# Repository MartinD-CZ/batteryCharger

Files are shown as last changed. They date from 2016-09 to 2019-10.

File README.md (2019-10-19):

# AVR-based universal battery charger

**UPDATE!** By popular request, I will be releasing a new version. Check [this post](http://embedblog.eu/?p=204) for more information.  
**UPDATE #2** I've abandoned the project, mostly because of time. What I have so far has been put into the 'unfinished-arduino' folder.

###### Overall
The charger is based on Atmega 328 (because it is dirt cheap) and utilizes its PWM to drive a FET, used as buck converter. There is also an 5110 LCD (again, less than 2 USD on Ebay) to show some basic menus and stuff. Most of the settings are adjustable on the go, so once you build and program it, you can use it without further reprogramming for all battery types and so on.

###### Batteries:
The charger supports all of the most used battery types - that is in my opinion NiCd, NiMH, Li-Ion and SLA. Li-Ion and SLA are charged in constant current-constant voltage mode, while Nickel based batteries are charged with constant current and terminated by about 5 methods (time out, overvoltage, overtemperature, -dV/dT, user termination). I have been using the charger for about a month before posting it here (tested everything except SLA, don’t have those on hand) and everything seems to work seamlessly. Maximum charging current is 3A, maximum charging voltage is almost Vin (that’s about 18V in my setup).

###### Discharge
The charger also comes with a discharge circuitry, used to:
	A) Measure battery capacity
	B) Discharge batteries before charging (useful with NiMH batteries to neutralize their memory effect)
The discharging current is fully adjustable from 0 to 3 amps, with undervoltage protection (again, fully adjustable). There is a small fan, which is automatically switched on when thermal power dissipation is bigger than 2 watts (you can change that, it depends on the size of your heatsink).

###### Power supply
Also in the menu you can find "constant C", "constant V" and "power supply" options. They provide you with simple power supply, useful for SOME applications. Because of the MCU limitations, the transient response time is relatively long, but on loads that do not change quickly, the MCU will react quickly enough. Maximum output voltage of the power supply is almost Vin and output current 3 A.

###### Project
This started as my own personal build, but since I spent a lot of time on it, I decided to publish it. For me, it works well, even for precise charging lithium batteries. 
It is inspired by AVR450, but 99% of the code is my work. I also used 5110 LCD driver library from Radu Motisan, see the 5110 files for credit.
I would like to hear some feedback on this project. What do you think about it? The total cost was less than 10 USD, which, I believe, is dirt cheap. Also, if there will be interest, I am thinking about porting this to STM32, as they are superior to 8-bit AVR and still very cheap. I would also include balancing circuitry. What do you think about that?

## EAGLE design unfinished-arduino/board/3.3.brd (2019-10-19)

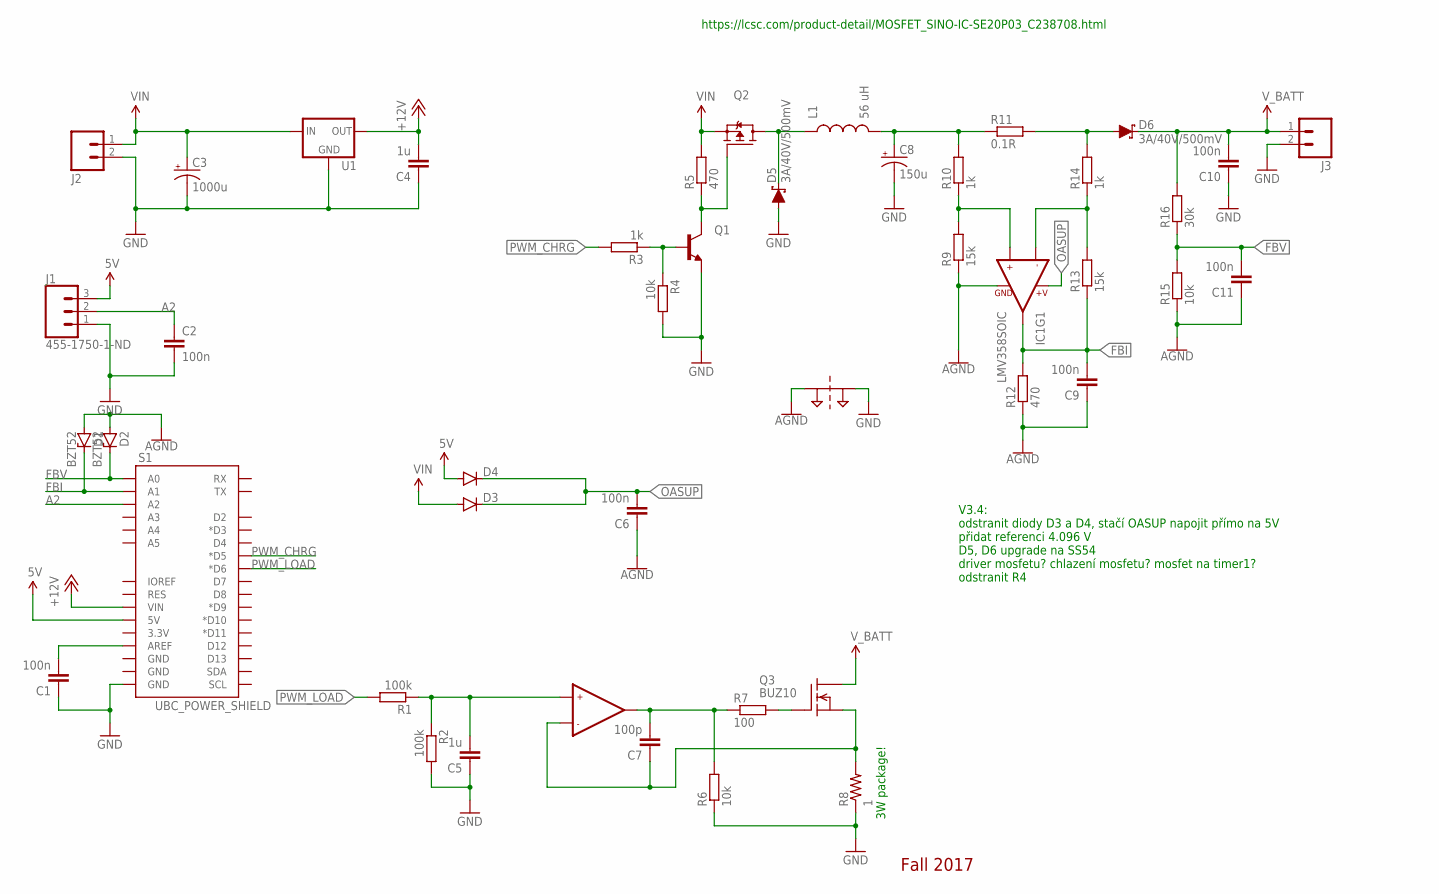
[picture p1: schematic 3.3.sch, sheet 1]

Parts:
C1, C2, C6, C9, C10, C11: 100n; C1206
C3: 1000u; CPOL-RADIAL-1000UF-25V
C4, C5: 1u; C1206
C7: 100p; C1206
C8: 150u; CPOL-RADIAL-100UF-25V
D1, D2: BZT52; SOD80C
D3, D4: DIODE-MINIMELF; MINIMELF
D5, D6: 3A/40V/500mV; SMA-DIODE
IC1: LMV358SOIC; SO08
J1: 455-1750-1-ND; 1X03
J2, J3: M025MM; SCREWTERMINAL-5MM-2
L1: 56 uH; CDRH125
PT1: 2PT_GND_TIE
Q1: 2N3904-MMBT; SOT23
Q2: FDD4141TO252; TO252
Q3: BUZ10; TO220
R1, R2: 100k; R1206
R3, R10, R14: 1k; R1206
R4, R6, R15: 10k; R1206
R5, R12: 470; R1206
R7: 100; R1206
R8: 1; 0617/22
R9, R13: 15k; R1206
R11: 0.1R; 0414/15
R16: 30k; R1206
S1: UBC_POWER_SHIELD; UBC_POWER
U1: V_REG_78XXSIDE; 78XXL

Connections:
5V: D4.A, J1.3, S1.5V; also elsewhere on the board
+12V: C4.2, S1.VIN, U1.OUT
A2: C2.1, J1.2, S1.A2
AGND: C6.1, C9.1, C11.1, D1.A, D2.A, IC1.4 (GND), PT1.P$1, R9.1, R12.1, R15.1
FBI: C9.2, D1.C, IC1.1 (OUT1), R12.2, R13.1, S1.A1
FBV: C11.2, D2.C, R15.2, R16.1, S1.A0
GND: C1.1, C2.2, C3.2 (-), C4.1, C5.1, C8.2 (-), C10.1, D5.A, J1.1, J2.2, J3.2, PT1.P$2, Q1.2 (E), R2.2, R4.2, R6.1, R8.1, S1.GND@0 (GND), U1.GND; also elsewhere on the board
unnamed: C8.1 (+), L1.2, R10.2, R11.1
unnamed: C1.2, S1.AREF
unnamed: IC1.3 (+IN1), R9.2, R10.1
unnamed: IC1.2 (-IN1), R13.2, R14.1
unnamed: D5.C, L1.1, Q2.3 (D)
unnamed: D6.A, R11.2, R14.2
unnamed: C7.2, IC1.7 (OUT2), R6.2, R7.1
unnamed: Q1.3 (C), Q2.1 (G), R5.1
unnamed: Q3.1 (G), R7.2
unnamed: C7.1, IC1.6 (-IN2), Q3.3 (S), R8.2
unnamed: C5.2, IC1.5 (+IN2), R1.1, R2.1
unnamed: Q1.1 (B), R3.1, R4.1
OASUP: C6.2, D3.C, D4.C, IC1.8 (+V)
PWM_CHRG: R3.2, S1.D5 (*D5)
PWM_LOAD: R1.2, S1.D6 (*D6)
VIN: C3.1 (+), D3.A, J2.1, Q2.2 (S), R5.2, U1.IN
V_BATT: C10.2, D6.C, J3.1, Q3.2 (D), R16.2

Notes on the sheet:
3W package!
Fall 2017
https://lcsc.com/product-detail/MOSFET_SINO-IC-SE20P03_C238708.html
V3.4: odstranit diody D3 a D4, stačí OASUP napojit přímo na 5V přidat referenci 4.096 V D5, D6 upgrade na SS54 driver mosfetu? chlazení mosfetu? mosfet na timer1? odstranit R4

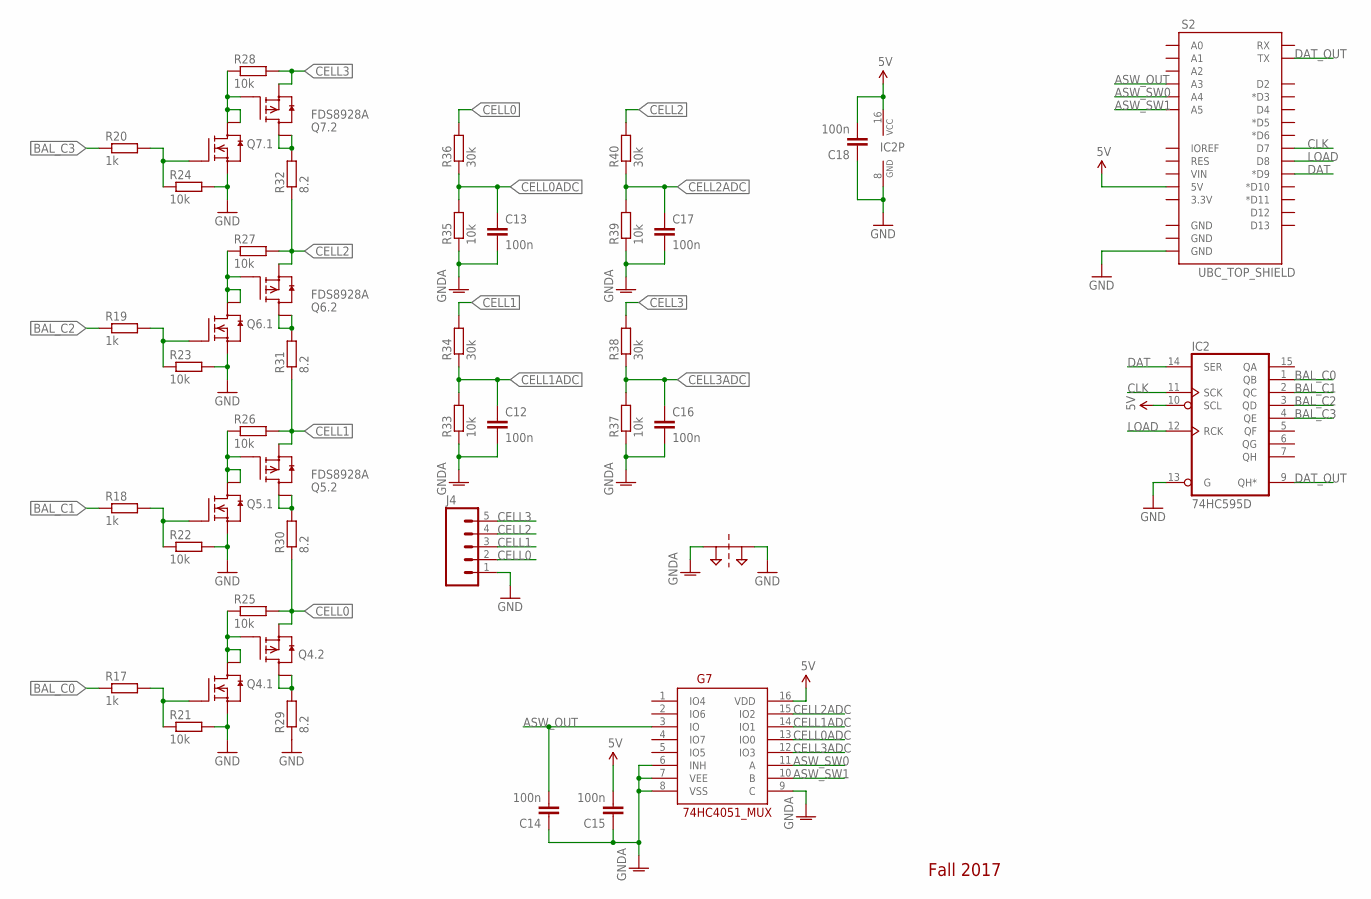
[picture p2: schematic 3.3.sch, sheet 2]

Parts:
C12, C13, C14, C15, C16, C17: 100n; C1206
C18: 100n; 1206
G7: 74HC4051_MUX; SO16
IC2: 74HC595D; SO16
J4: M05PTH; 1X05
PT2: 2PT_GND_TIE
Q4, Q5, Q6, Q7: FDS8928A; SO-8
R17, R18, R19, R20: 1k; R1206
R21, R22, R23, R24, R25, R26, R27, R28, R33, R35, R37, R39: 10k; R1206
R29, R30, R31, R32: 8.2; R2512
R34, R36, R38, R40: 30k; R1206
S2: UBC_TOP_SHIELD; UBC_TOP

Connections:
5V: C15.2, C18.2, G7.16 (VDD), IC2.10 (SCL), IC2.16 (VCC), S2.5V; also elsewhere on the board
ASW_OUT: C14.2, G7.3 (IO), S2.A3
ASW_SW0: G7.11 (A), S2.A4
ASW_SW1: G7.10 (B), S2.A5
BAL_C0: IC2.1 (QB), R17.1
BAL_C1: IC2.2 (QC), R18.1
BAL_C2: IC2.3 (QD), R19.1
BAL_C3: IC2.4 (QE), R20.1
CELL0: J4.2, Q4.3 (S), R25.2, R30.1, R36.2
CELL0ADC: C13.1, G7.13 (IO0), R35.2, R36.1
CELL1: J4.3, Q5.3 (S), R26.2, R31.1, R34.2
CELL1ADC: C12.1, G7.14 (IO1), R33.2, R34.1
CELL2: J4.4, Q6.3 (S), R27.2, R32.1, R40.2
CELL2ADC: C17.1, G7.15 (IO2), R39.2, R40.1
CELL3: J4.5, Q7.3 (S), R28.2, R38.2
CELL3ADC: C16.1, G7.12 (IO3), R37.2, R38.1
CLK: IC2.11 (SCK), S2.D7
DAT: IC2.14 (SER), S2.D9 (*D9)
DAT_OUT: IC2.9 (QH*), S2.TX
GND: C18.1, IC2.8 (GND), IC2.13 (G), J4.1, PT2.P$2, Q4.1 (S), Q5.1 (S), Q6.1 (S), Q7.1 (S), R21.2, R22.2, R23.2, R24.2, R29.1, S2.GND@0 (GND); also elsewhere on the board
GNDA: C12.2, C13.2, C14.1, C15.1, C16.2, C17.2, G7.6 (INH), G7.7 (VEE), G7.8 (VSS), G7.9 (C), PT2.P$1, R33.1, R35.1, R37.1, R39.1
LOAD: IC2.12 (RCK), S2.D8
unnamed: Q4.2 (G), R17.2, R21.1
unnamed: Q4.5 (D), Q4.6 (D), R29.2
unnamed: Q5.2 (G), R18.2, R22.1
unnamed: Q5.4 (G), Q5.7 (D), Q5.8 (D), R26.1
unnamed: Q5.5 (D), Q5.6 (D), R30.2
unnamed: Q6.2 (G), R19.2, R23.1
unnamed: Q6.4 (G), Q6.7 (D), Q6.8 (D), R27.1
unnamed: Q6.5 (D), Q6.6 (D), R31.2
unnamed: Q7.2 (G), R20.2, R24.1
unnamed: Q7.4 (G), Q7.7 (D), Q7.8 (D), R28.1
unnamed: Q7.5 (D), Q7.6 (D), R32.2
unnamed: Q4.4 (G), Q4.7 (D), Q4.8 (D), R25.1

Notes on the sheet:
Fall 2017

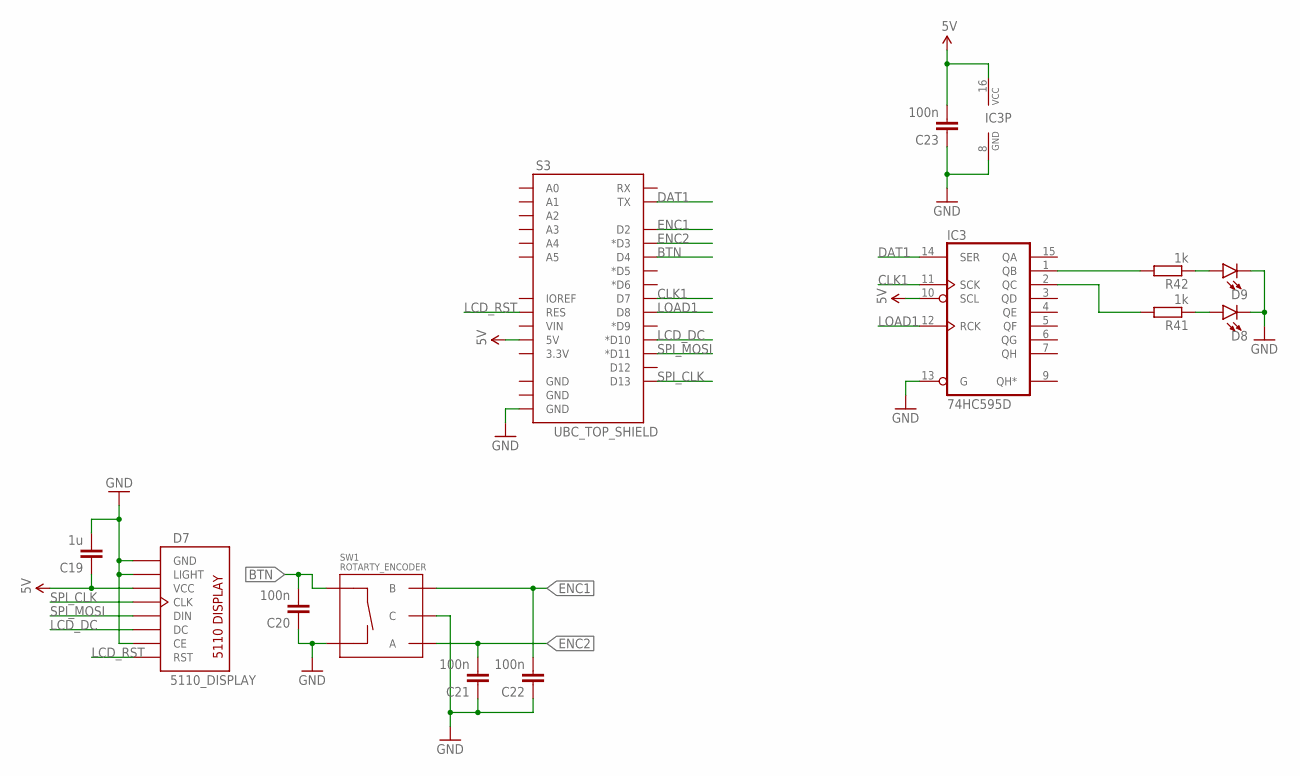
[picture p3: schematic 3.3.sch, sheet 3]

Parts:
C19: 1u; 1206
C20, C21, C22, C23: 100n; 1206
D7: 5110_DISPLAY; 5110_LAYOUT
D8, D9: LED5MM; LED_5MM
IC3: 74HC595D; SO16
R41, R42: 1k; R1206
S3: UBC_TOP_SHIELD; UBC_TOP
SW1: ROTARTY_ENCODER; ROTARY_ENC_PLAIN

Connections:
5V: C19.1, C23.2, D7.VCC, IC3.10 (SCL), IC3.16 (VCC), S3.5V; also elsewhere on the board
BTN: C20.2, S3.D4, SW1.SW+
CLK1: IC3.11 (SCK), S3.D7
DAT1: IC3.14 (SER), S3.TX
ENC1: C22.2, S3.D2, SW1.B
ENC2: C21.2, S3.D3 (*D3), SW1.A
GND: C19.2, C20.1, C21.1, C22.1, C23.1, D7.CE, D7.GND, D7.LIGHT, D8.K (C), D9.K (C), IC3.8 (GND), IC3.13 (G), S3.GND@0 (GND), SW1.C, SW1.SW-; also elsewhere on the board
LCD_DC: D7.DC, S3.D10 (*D10)
LCD_RST: D7.RST, S3.RES
LOAD1: IC3.12 (RCK), S3.D8
unnamed: IC3.1 (QB), R42.2
unnamed: IC3.2 (QC), R41.2
unnamed: D9.A, R42.1
unnamed: D8.A, R41.1
SPI_CLK: D7.CLK, S3.D13
SPI_MOSI: D7.DIN, S3.D11 (*D11)

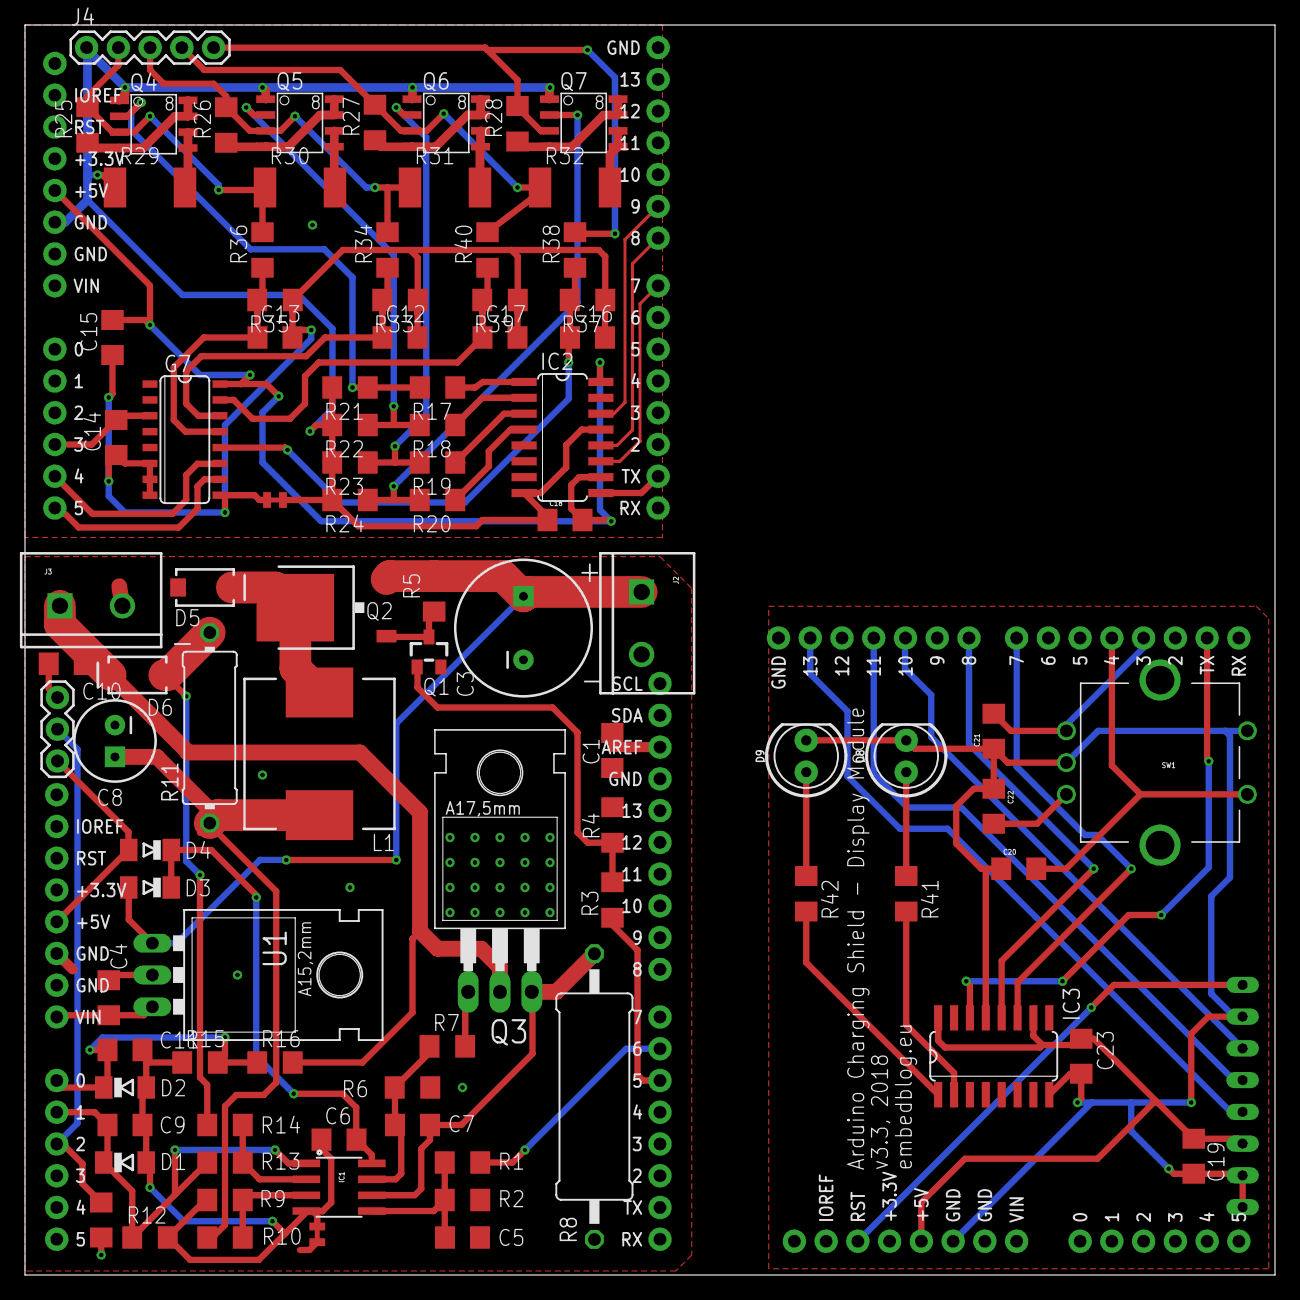
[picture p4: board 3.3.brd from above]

Board: 2 copper layers, 100.0 x 100.0 mm, 97 parts (0 on the bottom side), 70 nets.

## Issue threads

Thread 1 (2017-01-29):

V2

boelle, 2017-01-29:
Hi

have you started on V2 ?

I was looking for a charger most like yours, but have ideas for extra features

I have one of these old car chargers that can output about 15A.. would it be easy to expand the charger so it could go this high?

and if we fit one of those full graphics displays we would have a more space plus we could log things to a sd card?

just thoughts

boelle, 2017-01-29:
i read a bit about desulfators, they are great for car batteries that are going bad, sometimes you can bring them to life

and interesting a few people on the internet have used them with nimh cell's too

this one looks interesting: http://www.instructables.com/id/Desulfator-for-12V-Car-Batteries-in-an-Altoids-Ti/

MartinD-CZ, 2017-01-29:
Hi,

well, version 2 is scheduled, but I am currently very busy, so I think it
will not be out before the end od February. Well, theoretically it is only
a matter of changing components and their values for this thing to output
15A, but I have never tried more than 5A...
Well, of course, a better display would be a fine addition. But I was going
for as-cheap-as-possible, and I think that enough information fits on the
screen.

Regards,
Martin

On 29 January 2017 at 20:43, Bo Herrmannsen <notifications@github.com>
wrote:

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

boelle, 2017-01-29:
oki, could you put a reply more in here when you are about to publish it?

i might want to draw it in eagle schematic and do a real pcb of it.

would the desulfator idea be bad? and can it still fit on the same screen?

boelle, 2017-01-29:
oh.. i forgot... for the first version i see that you used eagle schematic also

how far have you come with V2? do you need to draw it first?

and also have you published the files for v1.3 ?

MartinD-CZ, 2017-01-30:
Hi,

as far as version 2 goes, I have the product working, what remains is
drawing the schematics, proper PCB layout and all the documentation. As for
the desulfator, I will have a look at it tomorrow, today I am busy.

Martin.

On 29 January 2017 at 21:50, Bo Herrmannsen <notifications@github.com>
wrote:

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

boelle, 2017-01-30:
np... cant wait to see what you have come up with :-D

sjdaliyan, 2018-03-17:
Any news of v2?

MartinD-CZ, 2018-03-17:
Hi,

well, I din't advance on it much. I have the board drawn, and manufactured,
but I did not get the time to populate, test, program and write about it.
So for now, the project is on hold, as I am working on different projects
now...
If I ever get back to it (and I want, don't get me wrong), I will certainly
publish it... But I do not have a clue as to when that might be.

Regards,
Martin

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

goosenphil, 2018-11-13:
Hi, since you've drawn the schematic in order to make the PCB, could you share the schematic and code with us in the meantime?

Since this is an open source project, some of us can take on the tasks you have not been able to reach.

It's fine if it's unfinished, we just want to see what you have so far.

Closed 2019-03-19.

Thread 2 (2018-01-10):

layout or schematics

repcsi, 2018-01-10:
Hello Martin,

I was wondering if there was a layout or schematics file in your project, because I couldn't find it in the atmel studio project directory.

Thanks!

MartinD-CZ, 2018-01-10:
Hi,

you can find the schematics on Instructables. However, the quality is very
poor. Anyways, this is an old project and I am working on a successor, so
if you wait a few weeks, you might be able to build the new version instead
of the old...

Regards,
Martin

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

Sausages69, 2018-01-14:
Hi Martin. This looks like a fantastic project!
Really looking forward to checking out the new version.

xtalgrwr, 2022-07-27:
Hello Martin,
Are you still active with the new version? Was there ever a PCB file?
Thank you. Please let us know.

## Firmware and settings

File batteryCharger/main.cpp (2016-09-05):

/*
 * AVR MultiChemistry charger
 * main.cpp file
 * (C) Martin Danek, 2016
 * madanek@post.cz
 * github.com/MartinD-CZ/AVRcharger
 */ 

#include <avr/wdt.h>
void wdt_init(void) __attribute__((naked)) __attribute__((section(".init3")));		//disables watchdog on startup

#include <inttypes.h>
#include "uart/uart.h"
#include <avr/io.h>
#include "header.h"
#include <util/delay.h>
#include <avr/interrupt.h>
#include "display/5110.h"
#include "display/menu.h"
extern LCD_5110 lcd;
#include "adc.h"
#include "batteryTypes/constantCV.h"
#include "batteryTypes/NiMH.h"
#include "functions.h"

//variables
volatile bool secondFlag;

char* mainMenuName = "Select mode: ";
char* mainMenuItems[5] = {"CHARGE", "DISCHARGE", "POWER SUPPLY", "ABOUT", "RESTART"};
char* chemistryMenuName = "Battery type:";
char* chemistryMenuItems[5] = {"Li-Ion/SLA", "NiCd/NiMH", "CONST V", "CONST C", "BACK TO MENU"};

int main(void)
{
    PORTD |= (1<<PORTD2)|(1<<PORTD3)|(1<<PORTD4);	//button pull up resistors 
	PORTB |= (1<<PORTB1)|(1<<PORTB2);

	DDRD |= (1<<DDD7);				//LED pins as outputs
	DDRB |= (1<<DDB0);	

	DDRD |= (1<<DDD5)|(1<<DDD6);	//pwm pins as outputs

	DDRC |= (1<<DDC4)|(1<<DDC5);	//UART and fan pins as outputs
	UART_PIN_HIGH;

	//setting up timer 1
	TCNT1 = 0;
	OCR1A = 19531;				//set the overflow value (overflow each second)
	TIMSK1 |= (1<<OCIE1A);		//enable CTC interrupt
	sei();						//globally enable interrupts

	ADC_setup();				
	lcdInit();					

	while (1) 
    {
		lcd.lcd_clear();
		float maxC, maxV, disC, minV;

		switch (drawSelectionMenu(mainMenuName, mainMenuItems))
		{
			case 0:		//charge
				uint8_t cells, hrs;
				switch(drawSelectionMenu(chemistryMenuName, chemistryMenuItems))
				{
					case 0:		//Li-Ion/SLA
						maxC = drawNumericalMenu("max charging\ncurrent [A]", 1.00);
						maxV = drawNumericalMenu("max battery\nvoltage [V]", 4.20);
						constantCVCharge(maxC, maxV);
						break;
					case 1:		//NiCd/NiMH
						maxC = drawNumericalMenu("charging\ncurrent [A]", 1.00);
						cells = drawNumericalMenu("# of\ncells", 1.00);
						hrs = drawNumericalMenu("charging\ntime [Hrs]", 7);
						chargeNiMH(maxC, cells, hrs);
						break;
					case 2:		//constant voltage
						maxV = drawNumericalMenu("output\nvoltage [V]", 5.00);
						constantVoltage(maxV);
						break;
					case 3:		//constant current
						maxC = drawNumericalMenu("output\ncurrent [A]", 1.00);
						constantCurrent(maxC);
						break;
					case 4:		//return
						break;
				}
				break;
			case 1:		//discharge
				disC = drawNumericalMenu("discharging\ncurrent [A]", 1.00);
				minV = drawNumericalMenu("minimal\nvoltage [A]", 1.00);
				discharge(disC, minV);
				break;
			case 2:		//power supply - constant current and voltage limited power supply (WARNING - long 
				maxV = drawNumericalMenu("output\nvoltage [V]", 5.00);
				maxC = drawNumericalMenu("current\nlimit [A]", 1.00);
				constantCV(maxV, maxC);
				break;
			case 3:		//about - just display a screen on the lcd
				lcd.lcd_clear();
				lcd.lcd_goto_xy_exact(0, 0);
				lcd.lcd_str(" AVR Charger   by M. Danek  V1.10  (c)2016   madanek\n   post.cz");
				while (!BTN_MIDDLE_PRESSED);
				while (BTN_MIDDLE_PRESSED);
				break;
			case 4:		//restart (set up a watchdog)
				wdt_enable(WDTO_15MS);
				while (1);
				break;
		}
    }
}

ISR(TIMER1_COMPA_vect)
{
	secondFlag = true;
}

void wdt_init(void)
{
	MCUSR = 0;
	wdt_disable();

	return;
}

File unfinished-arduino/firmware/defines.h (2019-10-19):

#pragma once

#define MODE_CHARGE			TCCR0A = (1 << COM0B1) | (1 << WGM00) | (1 << WGM01)
#define MODE_DISCHARGE		TCCR0A = (1 << COM0A1) | (1 << WGM00) | (1 << WGM01)
#define MODE_NONE			TCCR0A = (1 << WGM00) | (1 << WGM01)

#define CHARGE_PWM_DUTY		OCR0B
#define DISCHRG_PWM_DUTY	OCR0A

#define ADC_CHANNELS		2
#define ADC_START			ADCSRA |= (1 << ADSC)
#define ADC_CH_Vbat			0
#define ADC_CH_Ibat			1
#define VIN					5070		//in milivolts
#define ADC_RESOLUTION		(VIN/1024.0)

#define F_CPU				16000000UL

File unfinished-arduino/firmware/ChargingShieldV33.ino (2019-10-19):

/*
 Name:		ChargingShieldV33.ino
 Created:	3/24/2019 3:47:11 PM
 Author:	Martin Danek
*/

#include "util.h"
#include "defines.h"
#include <avr\delay.h>
#include <avr\interrupt.h>
#include "display.h"
#include "func.h"

const char* mainMenu[] = {"Chemistry", "Li-Ion/Pol", "NiMH/NiCd", "SLA/Pb-based", "About"};
const char* liIonMenu[] = {"Operation", "Charge", "Discharge", "Capacity Test", "Back"};

void setup()
{
	Serial.begin(115200);
	
	cli();
	init_pwm();
	MODE_NONE;

	init_gpio();

	init_adc();
	ADC_START;

	init_timer2();
	sei();

	Serial.println("Charging shield V3.3 ready!");

	display_init();
}

void loop()
{
	switch (display_drawMenu(mainMenu))
	{
	case 0:		//Li-Ion
	{
		switch (display_drawMenu(liIonMenu))
		{
		case 0:		//Li-Ion: Charge
		{
			uint16_t tgtVolt = display_drawNumMenu("MAX VOLTAGE", "mV", 4200, 1000, 10000, 50);
			uint16_t tgtAmp = display_drawNumMenu("MAX CURRENT", "mA", 1000, 50, 2000, 100);
			uint16_t minAmp = display_drawNumMenu("CUTOFF CURR", "mA", 100, 50, 2000, 100);
			func_chargeLi(tgtVolt, tgtAmp, minAmp);
			break;
		}
		case 1:		//Li-Ion: Discharge
		{
			uint16_t tgtAmp = display_drawNumMenu("CURRENT", "mA", 1000, 100, 1500, 100);
			uint16_t minVolt = display_drawNumMenu("MIN. VOLT", "mV", 2500, 500, 10000, 100);
			func_discharge(tgtAmp, minVolt);
			break;
		}
		case 2:		//Li-Ion: Capacity test
		{
			display_msg("Error 0.2", "Not Available");
			break;
		}
		default:
			return;
		}
		break;
	}
	case 1:		//NiMH/NiCd
	{
		display_msg("Error 1", "Not Available");
		break;
	}
	case 2:		//SLA/Pb-based
	{
		display_msg("Error 2", "Not Available");
		break;
	}
	case 3:		//settings
	{
		display_msg("Error 3", "Not Available");
		break;
	}
	default:
	{
		display_msg("Error 4", "Out of range");
		break;
	}

	}
	
	
	/*uint16_t volts = read_data(ADC_CH_Vbat);
	uint16_t amps = read_data(ADC_CH_Ibat);
	uint32_t watts = volts * amps / 1000;
	
	Serial.print("Vbat: ");
	Serial.print(volts);
	Serial.print(" mV; Ibat: ");
	Serial.print(amps);
	Serial.print(" mA; PWM: ");
	Serial.print(CHARGE_PWM_DUTY);
	//Serial.print(" mV; PWM: ");
	//.print(DISCHRG_PWM_DUTY);
	Serial.print("; P: ");
	Serial.print(watts);
	Serial.println(" W");
	_delay_ms(1000);*/
}

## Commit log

2016-09-05 Version 1.1
    As of now, everything is working. The code is not nice (however, it
    could be worse), but works.
    [results.xlsx]
2016-09-05 Version 1.1.1
    deleted unnecessary files
    [results.xlsx]
2019-10-19 added experimental
    [3.3.brd, 3.3.sch, 3.4.brd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]

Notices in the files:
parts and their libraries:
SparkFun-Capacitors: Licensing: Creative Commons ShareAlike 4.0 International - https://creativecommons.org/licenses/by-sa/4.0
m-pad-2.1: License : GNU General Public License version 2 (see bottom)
